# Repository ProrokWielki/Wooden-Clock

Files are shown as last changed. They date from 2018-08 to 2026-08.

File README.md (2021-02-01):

# PROJECT IN PROGRESS #

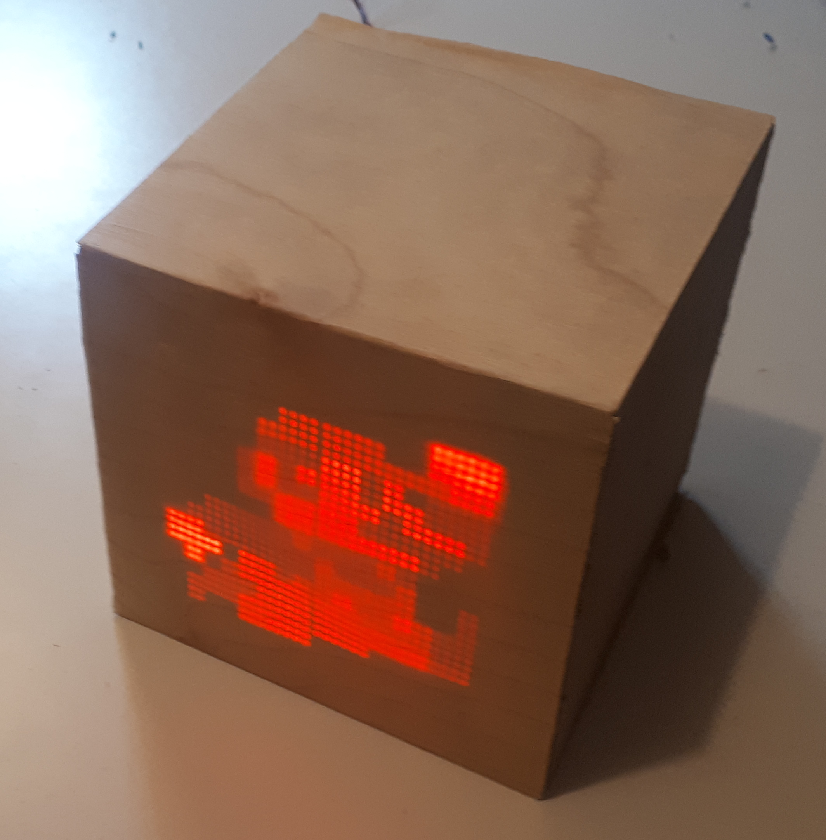
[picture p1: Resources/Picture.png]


A seamless wooden cube with invisble (when turned off) screen.

## how to compile ##

### prerequisites ###

* python >= 3.6
* arm_none_eabi_gcc

### compilation ###

```
git clone https://github.com/ProrokWielki/Wooden-Clock.git
git submodule update --init

pip install py_buildsystem

cd Software/config/py_buildsystem

py_buildsystem -pcc G++_ARM_Config.yaml -pc WoodenClock.yaml
```

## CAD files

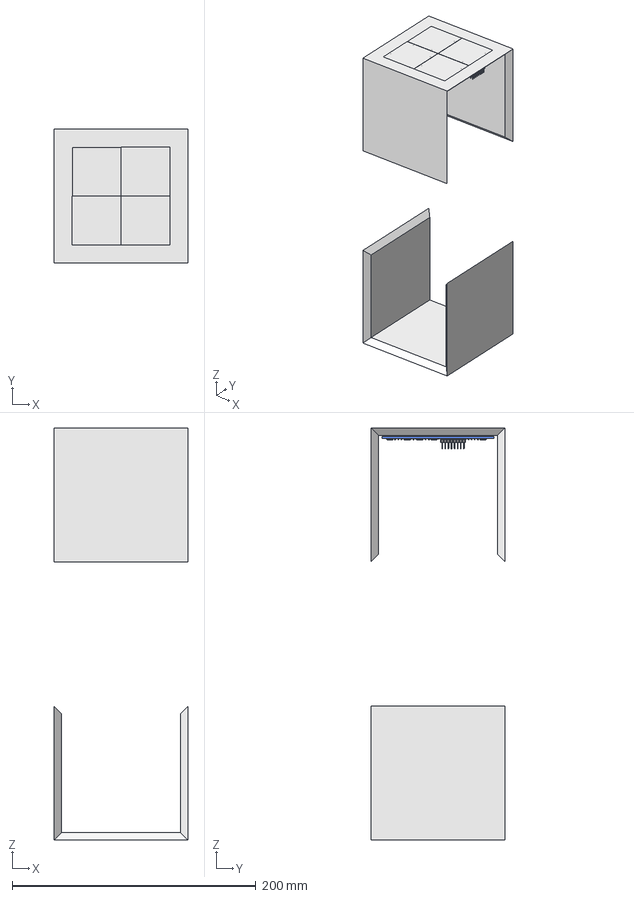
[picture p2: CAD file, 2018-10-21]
Hardware/Casing/Combined.FCStd
110.0 x 110.0 x 338.3 mm
Pcb
R_0805_2012Metric_063
R_0805_2012Metric_064
R_0805_2012Metric_065
R_0805_2012Metric_066
R_0805_2012Metric_067
R_0805_2012Metric_068
R_0805_2012Metric_069
R_0805_2012Metric_070
R_0805_2012Metric_071
R_0805_2012Metric_072
R_0805_2012Metric_073
R_0805_2012Metric_074
R_0805_2012Metric_075
R_0805_2012Metric_076
R_0805_2012Metric_077
R_0805_2012Metric_078
R_0805_2012Metric_079
R_0805_2012Metric_080
R_0805_2012Metric_081
R_0805_2012Metric_082
R_0805_2012Metric_083
R_0805_2012Metric_084
R_0805_2012Metric_085
R_0805_2012Metric_086
R_0805_2012Metric_087
R_0805_2012Metric_088
R_0805_2012Metric_089
R_0805_2012Metric_090
R_0805_2012Metric_091
R_0805_2012Metric_092
R_0805_2012Metric_093
R_0805_2012Metric_094
SOT23_
SOT23_001
SOT23_002
SOT23_003
SOT23_004
SOT23_005
SOT23_006
SOT23_007
SOT23_008
SOT23_009
SOT23_010
SOT23_011
SOT23_012
SOT23_013
SOT23_014
SOT23_015
SOT23_016
SOT23_017
SOT23_018
SOT23_019
SOT23_020
SOT23_021
SOT23_022
SOT23_023
SOT23_024
SOT23_025
SOT23_026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

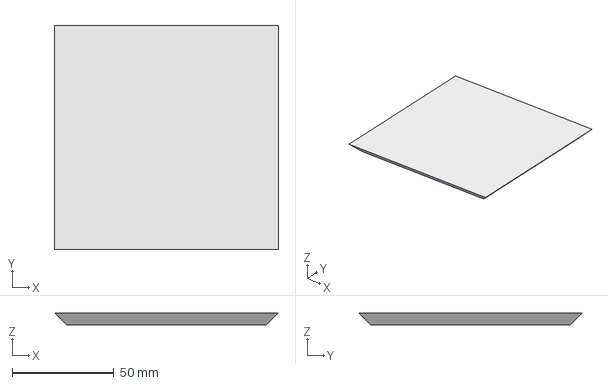
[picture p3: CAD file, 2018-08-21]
Hardware/Casing/SidePlate.FCStd
110.0 x 110.0 x 6.00 mm

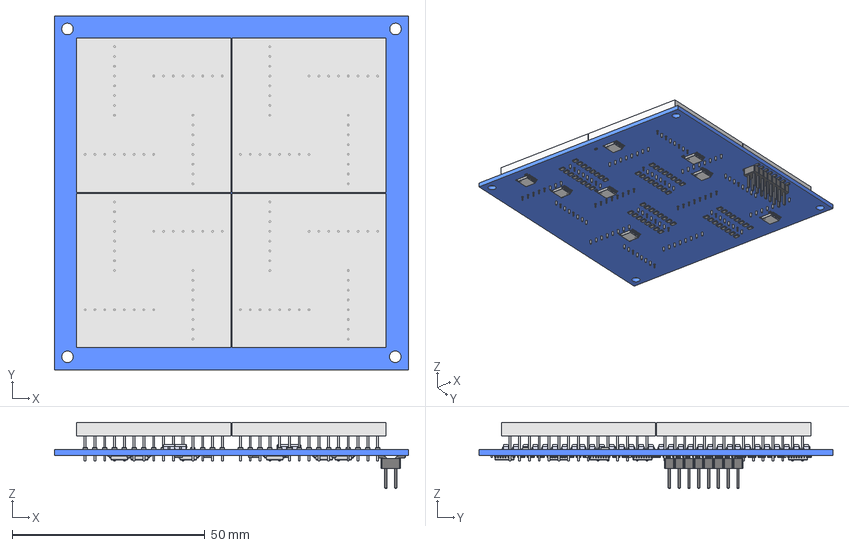
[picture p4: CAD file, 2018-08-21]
Hardware/Casing/DisplayBoard.FCStd
91.8 x 91.6 x 17.1 mm
Pcb
R_0805_2012Metric_063
R_0805_2012Metric_064
R_0805_2012Metric_065
R_0805_2012Metric_066
R_0805_2012Metric_067
R_0805_2012Metric_068
R_0805_2012Metric_069
R_0805_2012Metric_070
R_0805_2012Metric_071
R_0805_2012Metric_072
R_0805_2012Metric_073
R_0805_2012Metric_074
R_0805_2012Metric_075
R_0805_2012Metric_076
R_0805_2012Metric_077
R_0805_2012Metric_078
R_0805_2012Metric_079
R_0805_2012Metric_080
R_0805_2012Metric_081
R_0805_2012Metric_082
R_0805_2012Metric_083
R_0805_2012Metric_084
R_0805_2012Metric_085
R_0805_2012Metric_086
R_0805_2012Metric_087
R_0805_2012Metric_088
R_0805_2012Metric_089
R_0805_2012Metric_090
R_0805_2012Metric_091
R_0805_2012Metric_092
R_0805_2012Metric_093
R_0805_2012Metric_094
SOT23_
SOT23_001
SOT23_002
SOT23_003
SOT23_004
SOT23_005
SOT23_006
SOT23_007
SOT23_008
SOT23_009
SOT23_010
SOT23_011
SOT23_012
SOT23_013
SOT23_014
SOT23_015
SOT23_016
SOT23_017
SOT23_018
SOT23_019
SOT23_020
SOT23_021
SOT23_022
SOT23_023
SOT23_024
SOT23_025
SOT23_026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

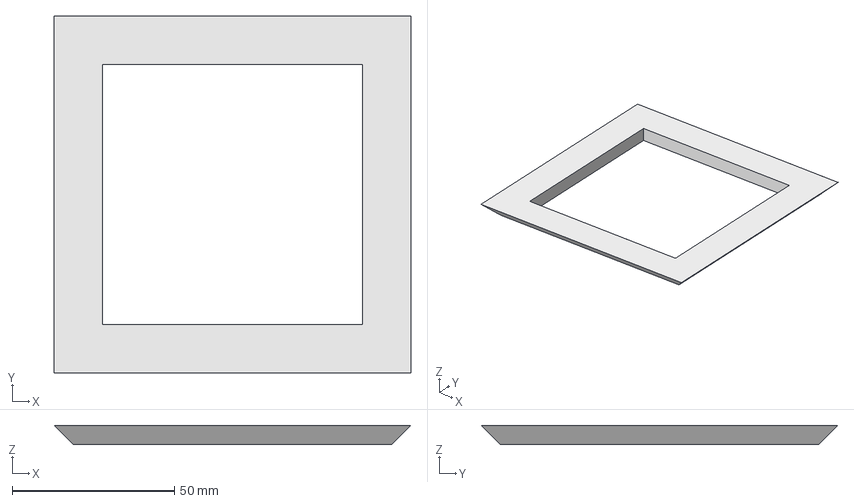
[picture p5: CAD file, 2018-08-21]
Hardware/Casing/FacePlate.FCStd
110.0 x 110.0 x 6.00 mm

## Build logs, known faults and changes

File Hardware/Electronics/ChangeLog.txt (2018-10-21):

0.1.0
  - first releas of the display board

0.1.1
  - fixed swapped drains and sources on the MOSFETs

0.2.0
  - changed P1 from 1x10 header to 2x8 header
  - separated all I2C - all the TLCs can be programed at the same time
  - all I2C are available on the P1

0.2.1
  - silk screens elements arranged
  - added author, board name and board version on the bottom silk screen

1.0.0
  - moved vias from the capacitor pads
  - added github link to silksreen

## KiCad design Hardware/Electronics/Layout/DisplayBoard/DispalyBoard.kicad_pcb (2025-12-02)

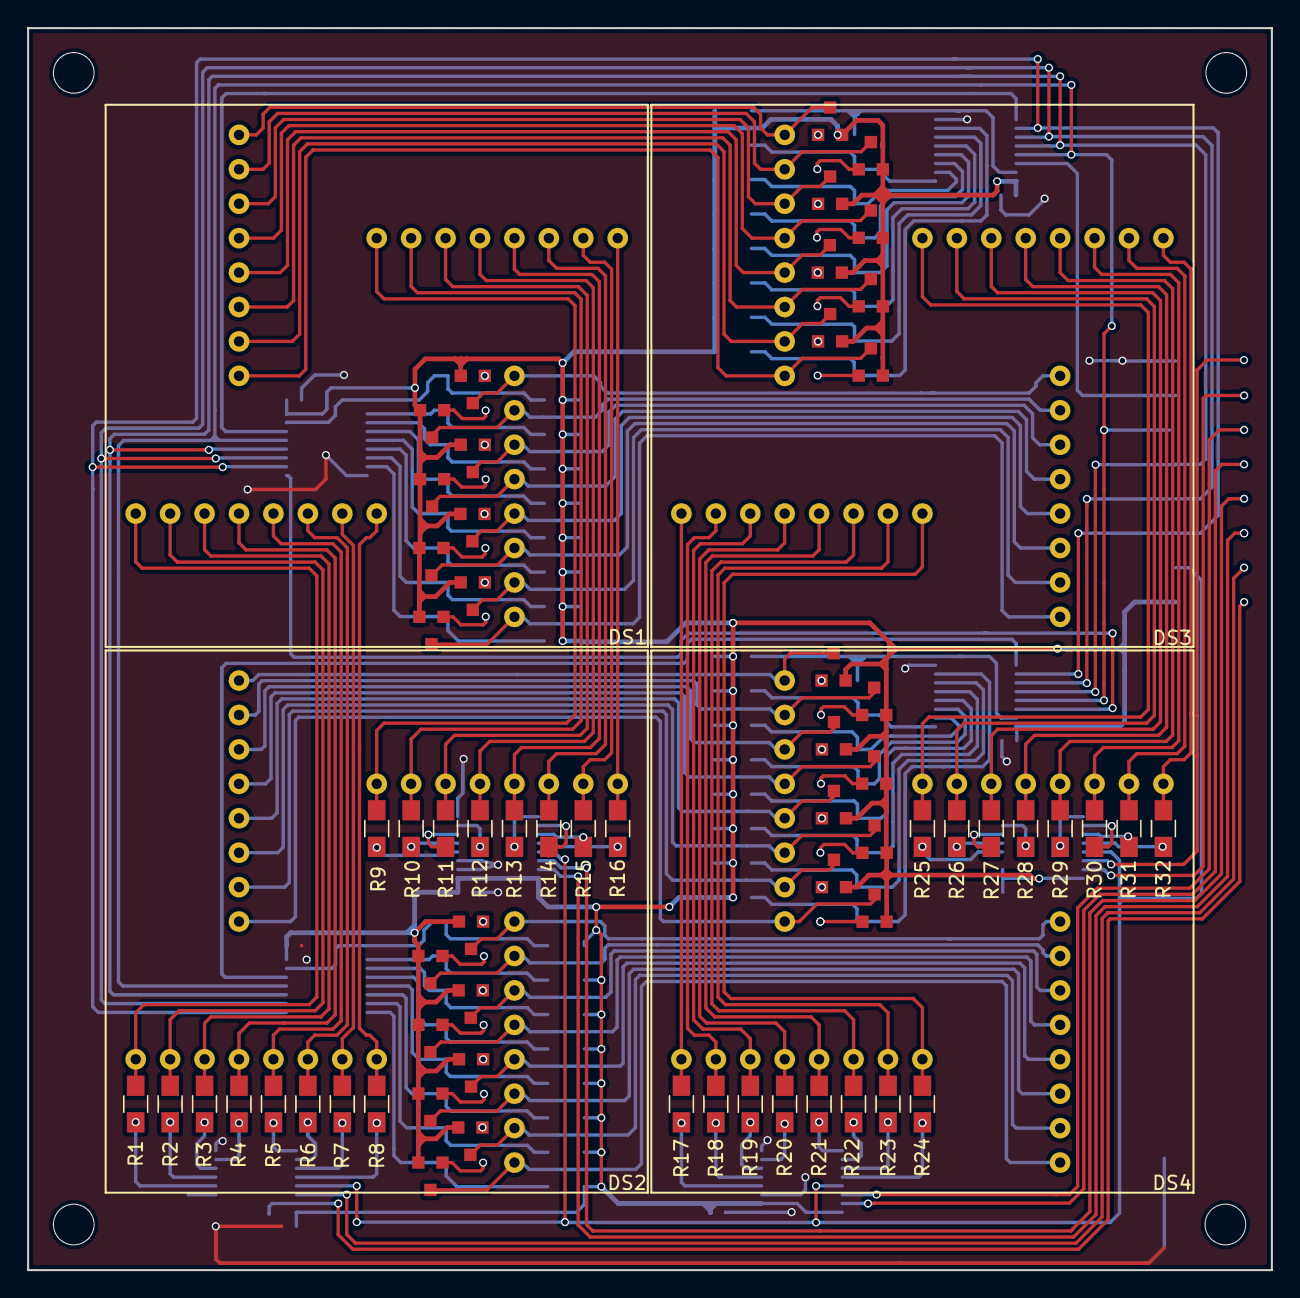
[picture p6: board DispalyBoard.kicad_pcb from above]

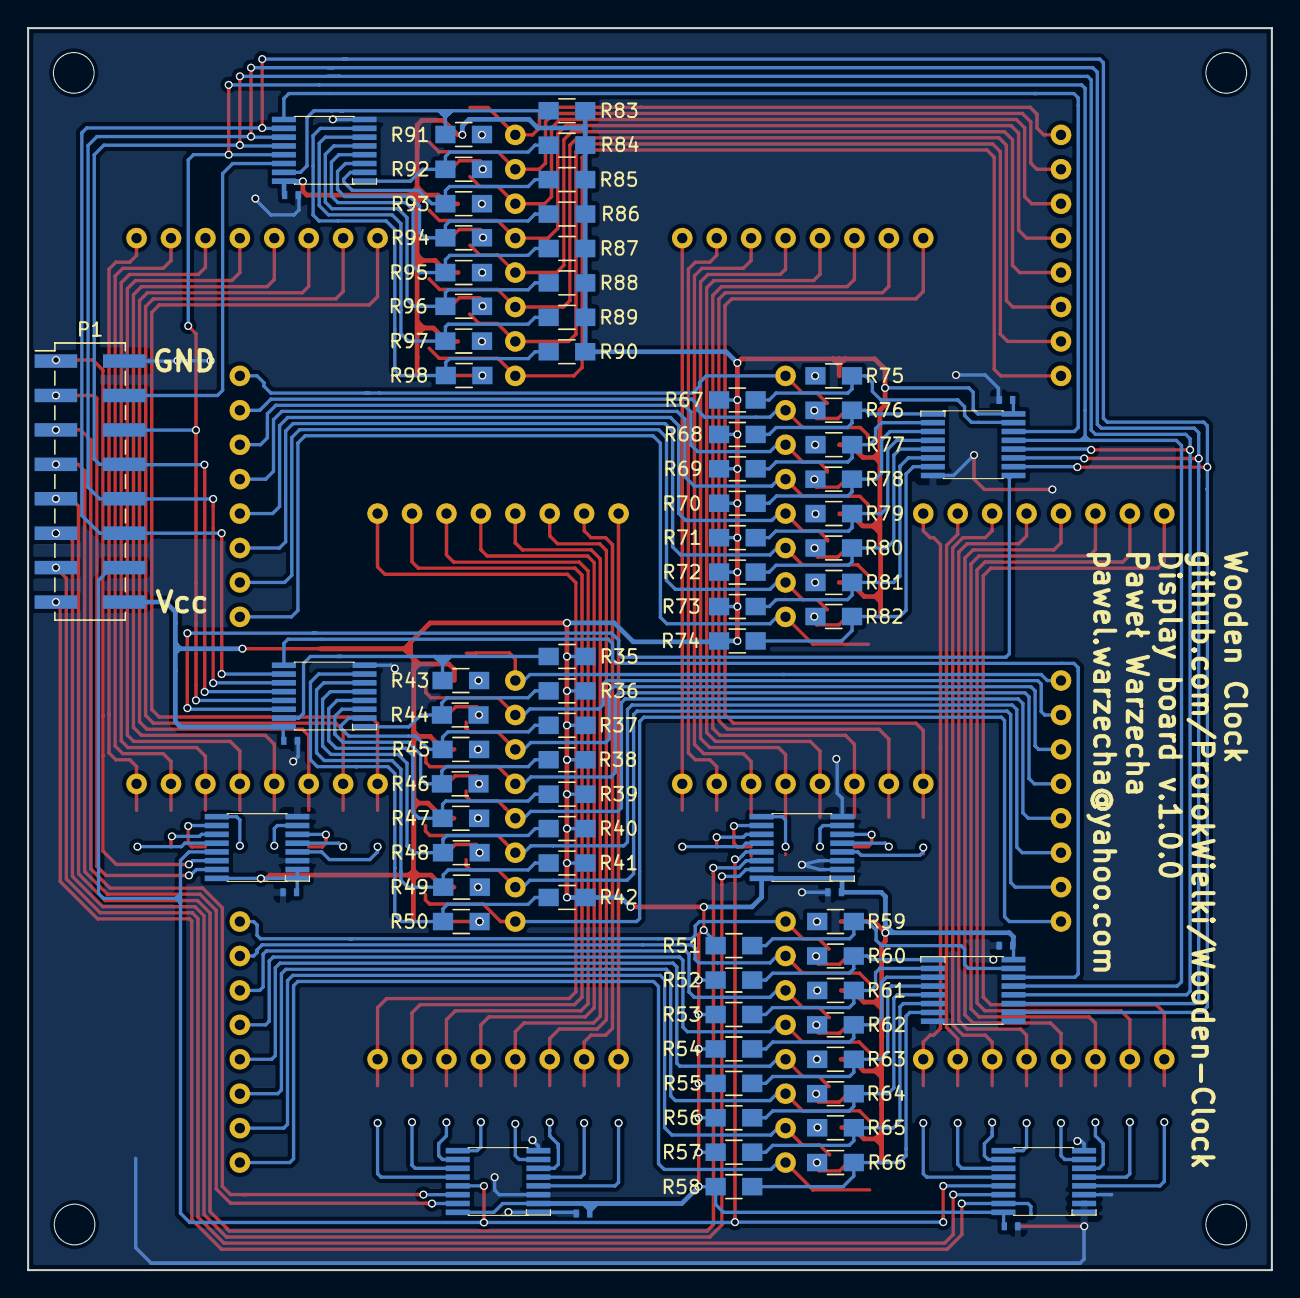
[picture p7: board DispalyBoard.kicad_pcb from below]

Board: 2 copper layers, 91.8 x 91.6 mm, 149 parts (81 on the bottom side), 179 nets.

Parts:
C1, C2, C3, C4, C5, C6, C7, C8: 100n; C0402
DS1, DS2, DS3, DS4: LM-1616015-CC; LM1616X15
P1: CONN_02X08; Pin_Header_Straight_2x08_Pitch2.54mm_SMD
Q1, Q2, Q3, Q4, Q5, Q6, Q7, Q8, Q9, Q10, Q11, Q12, Q13, Q14, Q15, Q16, Q17, Q18, Q19, Q20, Q21, Q22, Q23, Q24, Q25, Q26, Q27, Q28, Q29, Q30, Q31, Q32: TSM3401; SOT23-3
R1, R2, R3, R4, R5, R6, R7, R8, R9, R10, R11, R12, R13, R14, R15, R16, R17, R18, R19, R20, R21, R22, R23, R24, R25, R26, R27, R28, R29, R30, R31, R32: 47; R_0805_HandSoldering
R35, R36, R37, R38, R39, R40, R41, R42, R51, R52, R53, R54, R55, R56, R57, R58, R67, R68, R69, R70, R71, R72, R73, R74, R83, R84, R85, R86, R87, R88, R89, R90: 100k; R_0805_HandSoldering
R43, R44, R45, R46, R47, R48, R49, R50, R59, R60, R61, R62, R63, R64, R65, R66, R75, R76, R77, R78, R79, R80, R81, R82, R91, R92, R93, R94, R95, R96, R97, R98: 100; R_0805_HandSoldering
U1, U2, U3, U4: TLC59208F; TSSOP16
U5, U6, U7, U8: 74HC595; TSSOP16

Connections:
+3V3: C1.1, C2.1, C3.1, C4.1, C5.1, C6.1, C7.1, C8.1, P1.16, Q1.2, Q2.2, Q3.2, Q4.2, Q5.2, Q6.2, Q7.2, Q8.2, Q9.2, Q10.2, Q11.2, Q12.2, Q13.2, Q14.2, Q15.2, Q16.2, Q17.2, Q18.2, Q19.2, Q20.2, Q21.2, Q22.2, Q23.2, Q24.2, Q25.2, Q26.2, Q27.2, Q28.2, Q29.2, Q30.2, Q31.2, Q32.2, R35.1, R36.1, R37.1, R38.1, R39.1, R40.1, R41.1, R42.1, R51.1, R52.1, R53.1, R54.1, R55.1, R56.1, R57.1, R58.1, R67.1, R68.1, R69.1, R70.1, R71.1, R72.1, R73.1, R74.1, R83.1, R84.1, R85.1, R86.1, R87.1, R88.1, R89.1, R90.1, U1.16, U2.1, U2.16, U3.2, U3.16, U4.1, U4.2, U4.16, U5.16, U6.16, U7.16, U8.16
/C1: DS1.1, DS2.1, R1.2
/C2: DS1.2, DS2.2, R2.2
/C3: DS1.3, DS2.3, R3.2
/C4: DS1.4, DS2.4, R4.2
/C5: DS1.5, DS2.5, R5.2
/C6: DS1.6, DS2.6, R6.2
/C7: DS1.7, DS2.7, R7.2
/C8: DS1.8, DS2.8, R8.2
/C9: DS1.24, DS2.24, R9.2
/C10: DS1.23, DS2.23, R10.2
/C11: DS1.22, DS2.22, R11.2
/C12: DS1.21, DS2.21, R12.2
/C13: DS1.20, DS2.20, R13.2
/C14: DS1.19, DS2.19, R14.2
/C15: DS1.18, DS2.18, R15.2
/C16: DS1.17, DS2.17, R16.2
/C17: DS3.1, DS4.1, R17.2
/C18: DS3.2, DS4.2, R18.2
/C19: DS3.3, DS4.3, R19.2
/C20: DS3.4, DS4.4, R20.2
/C21: DS3.5, DS4.5, R21.2
/C22: DS3.6, DS4.6, R22.2
/C23: DS3.7, DS4.7, R23.2
/C24: DS3.8, DS4.8, R24.2
/C25: DS3.24, DS4.24, R25.2
/C26: DS3.23, DS4.23, R26.2
/C27: DS3.22, DS4.22, R27.2
/C28: DS3.21, DS4.21, R28.2
/C29: DS3.20, DS4.20, R29.2
/C30: DS3.19, DS4.19, R30.2
/C31: DS3.18, DS4.18, R31.2
/C32: DS3.17, DS4.17, R32.2
/CLK: P1.10, U5.11, U6.11, U7.11, U8.11
/LAT: P1.8, U5.12, U6.12, U7.12, U8.12
/MosfetMultiplexer9-16/SIN: U7.14, U8.9
/MosfetMultiplexer17-24/SIN: U5.14, U7.9
/MosfetMultiplexer25-32/SIN: U5.9, U6.14
/OE: P1.6, U5.13, U6.13, U7.13, U8.13
/R1: DS1.25, DS3.25, Q25.3
/R2: DS1.26, DS3.26, Q26.3
/R3: DS1.27, DS3.27, Q27.3
/R4: DS1.28, DS3.28, Q28.3
/R5: DS1.29, DS3.29, Q29.3
/R6: DS1.30, DS3.30, Q30.3
/R7: DS1.31, DS3.31, Q31.3
/R8: DS1.32, DS3.32, Q32.3
/R9: DS1.16, DS3.16, Q17.3
/R10: DS1.15, DS3.15, Q18.3
/R11: DS1.14, DS3.14, Q19.3
/R12: DS1.13, DS3.13, Q20.3
/R13: DS1.12, DS3.12, Q21.3
/R14: DS1.11, DS3.11, Q22.3
/R15: DS1.10, DS3.10, Q23.3
/R16: DS1.9, DS3.9, Q24.3
/R17: DS2.25, DS4.25, Q1.3
/R18: DS2.26, DS4.26, Q2.3
/R19: DS2.27, DS4.27, Q3.3
/R20: DS2.28, DS4.28, Q4.3
/R21: DS2.29, DS4.29, Q5.3
/R22: DS2.30, DS4.30, Q6.3
/R23: DS2.31, DS4.31, Q7.3
/R24: DS2.32, DS4.32, Q8.3
/R25: DS2.16, DS4.16, Q9.3
/R26: DS2.15, DS4.15, Q10.3
/R27: DS2.14, DS4.14, Q11.3
/R28: DS2.13, DS4.13, Q12.3
/R29: DS2.12, DS4.12, Q13.3
/R30: DS2.11, DS4.11, Q14.3
/R31: DS2.10, DS4.10, Q15.3
/R32: DS2.9, DS4.9, Q16.3
/RESET: P1.14, U1.13, U2.13, U3.13, U4.13
/RST: P1.12, U5.10, U6.10, U7.10, U8.10
/SCL1: P1.13, U1.14
/SCL2: P1.9, U2.14
/SCL3: P1.5, U3.14
/SCL4: P1.1, U4.14
/SDA1: P1.15, U1.15
/SDA2: P1.11, U2.15
/SDA3: P1.7, U3.15
/SDA4: P1.3, U4.15
/SIN: P1.4, U8.14
GND: C1.2, C2.2, C3.2, C4.2, C5.2, C6.2, C7.2, C8.2, P1.2, U1.1, U1.2, U1.3, U1.8, U2.2, U2.3, U2.8, U3.1, U3.3, U3.8, U4.3, U4.8, U5.8, U6.8, U7.8, U8.8
unnamed: Q1.1, R43.1
unnamed: Q2.1, R44.1
unnamed: Q3.1, R45.1
unnamed: Q4.1, R46.1
unnamed: Q5.1, R47.1
unnamed: Q6.1, R48.1
unnamed: Q7.1, R49.1
unnamed: Q8.1, R50.1
unnamed: Q9.1, R59.1
unnamed: Q10.1, R60.1
unnamed: Q11.1, R61.1
unnamed: Q12.1, R62.1
unnamed: Q13.1, R63.1
unnamed: Q14.1, R64.1
unnamed: Q15.1, R65.1
unnamed: Q16.1, R66.1
unnamed: Q17.1, R75.1
unnamed: Q18.1, R76.1
unnamed: Q19.1, R77.1
unnamed: Q20.1, R78.1
unnamed: Q21.1, R79.1
unnamed: Q22.1, R80.1
unnamed: Q23.1, R81.1
unnamed: Q24.1, R82.1
unnamed: Q25.1, R91.1
unnamed: Q26.1, R92.1
unnamed: Q27.1, R93.1
unnamed: Q28.1, R94.1
unnamed: Q29.1, R95.1
unnamed: Q30.1, R96.1
unnamed: Q31.1, R97.1
unnamed: Q32.1, R98.1
unnamed: R1.1, U1.4
unnamed: R2.1, U1.5
unnamed: R3.1, U1.6
unnamed: R4.1, U1.7
unnamed: R5.1, U1.9
unnamed: R6.1, U1.10
unnamed: R7.1, U1.11
unnamed: R8.1, U1.12
unnamed: R9.1, U2.4
unnamed: R10.1, U2.5
unnamed: R11.1, U2.6
unnamed: R12.1, U2.7
unnamed: R13.1, U2.9
unnamed: R14.1, U2.10
unnamed: R15.1, U2.11
unnamed: R16.1, U2.12
unnamed: R17.1, U3.4
unnamed: R18.1, U3.5
unnamed: R19.1, U3.6
unnamed: R20.1, U3.7
unnamed: R21.1, U3.9
unnamed: R22.1, U3.10
unnamed: R23.1, U3.11
unnamed: R24.1, U3.12
unnamed: R25.1, U4.4
unnamed: R26.1, U4.5
unnamed: R27.1, U4.6
unnamed: R28.1, U4.7
unnamed: R29.1, U4.9
unnamed: R30.1, U4.10
unnamed: R31.1, U4.11
unnamed: R32.1, U4.12
unnamed: R35.2, R43.2, U5.15
unnamed: R36.2, R44.2, U5.1
unnamed: R37.2, R45.2, U5.2
unnamed: R38.2, R46.2, U5.3
unnamed: R39.2, R47.2, U5.4
unnamed: R40.2, R48.2, U5.5
unnamed: R41.2, R49.2, U5.6
unnamed: R42.2, R50.2, U5.7
unnamed: R51.2, R59.2, U6.15
unnamed: R52.2, R60.2, U6.1
unnamed: R53.2, R61.2, U6.2
unnamed: R54.2, R62.2, U6.3
unnamed: R55.2, R63.2, U6.4
unnamed: R56.2, R64.2, U6.5
unnamed: R57.2, R65.2, U6.6
unnamed: R58.2, R66.2, U6.7
unnamed: R67.2, R75.2, U7.15
unnamed: R68.2, R76.2, U7.1
unnamed: R69.2, R77.2, U7.2
unnamed: R70.2, R78.2, U7.3
unnamed: R71.2, R79.2, U7.4
unnamed: R72.2, R80.2, U7.5
unnamed: R73.2, R81.2, U7.6
unnamed: R74.2, R82.2, U7.7
unnamed: R83.2, R91.2, U8.15
unnamed: R84.2, R92.2, U8.1
unnamed: R85.2, R93.2, U8.2
unnamed: R86.2, R94.2, U8.3
unnamed: R87.2, R95.2, U8.4
unnamed: R88.2, R96.2, U8.5
unnamed: R89.2, R97.2, U8.6
unnamed: R90.2, R98.2, U8.7

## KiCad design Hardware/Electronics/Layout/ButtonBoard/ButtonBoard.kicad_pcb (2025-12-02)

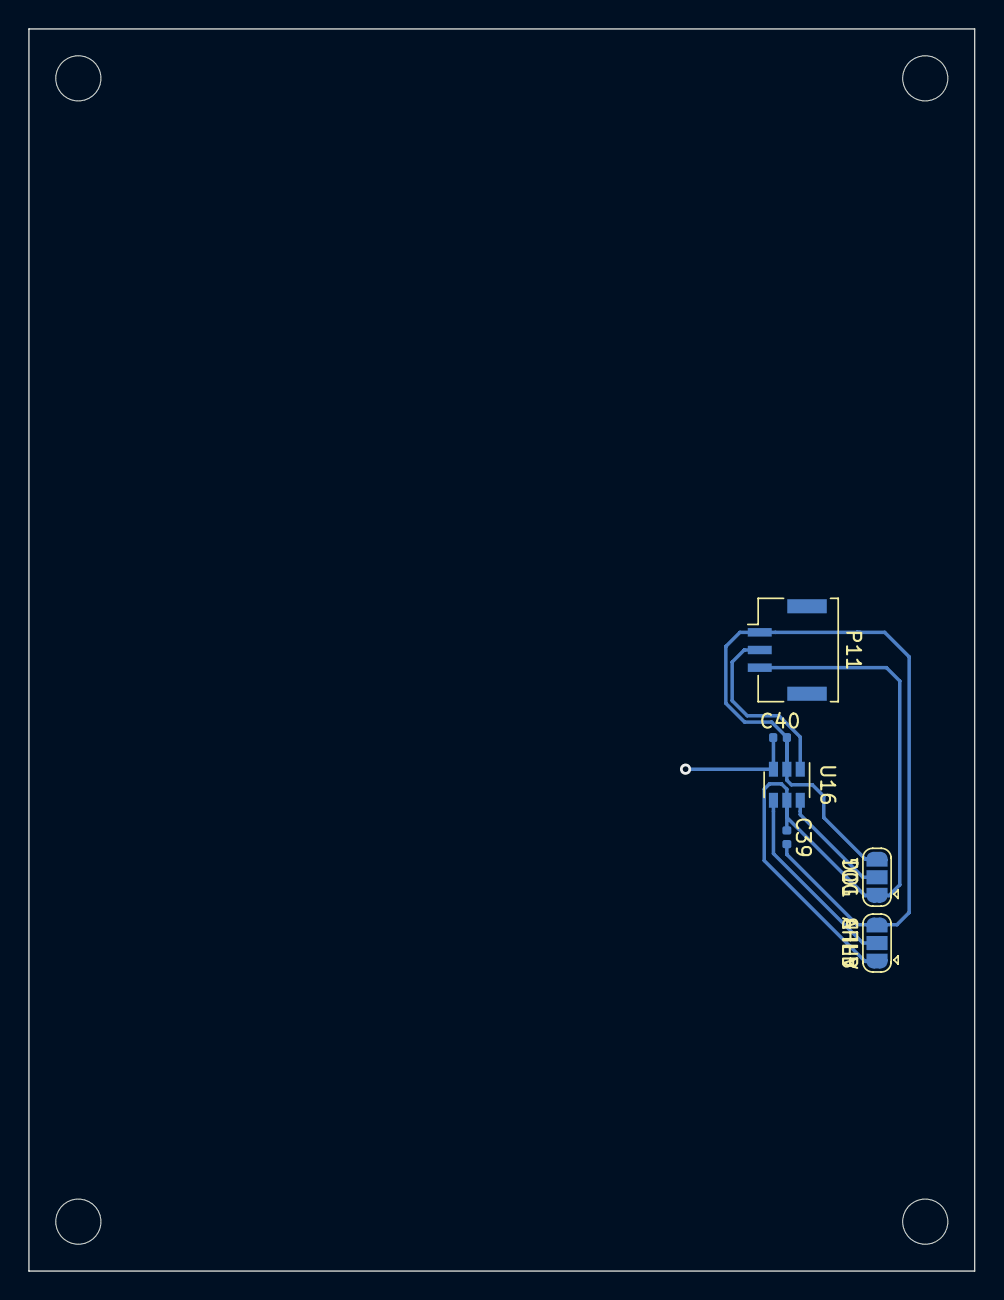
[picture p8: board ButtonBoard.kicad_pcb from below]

Board: 2 copper layers, 67.0 x 88.0 mm, 6 parts (6 on the bottom side), 6 nets.

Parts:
AHLB: AHLB; SolderJumper-3_P1.3mm_Open_RoundedPad1.0x1.5mm
C39: 1u; C_0402_1005Metric
C40: <50p; C_0402_1005Metric
P11: CONN_01X03; Molex_CLIK-Mate_502382-0370_1x03-1MP_P1.25mm_Vertical
TOG: TOG; SolderJumper-3_P1.3mm_Open_RoundedPad1.0x1.5mm
U16: TTP223; SOT-23-6

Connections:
+3V3: AHLB.1, C39.1, P11.3, TOG.1, U16.5
GND: AHLB.3, C39.2, C40.2, P11.1, TOG.3, U16.2
unnamed: AHLB.2, U16.4
unnamed: TOG.2, U16.6
OUTPUT: P11.2, U16.1
PAD: C40.1, U16.3

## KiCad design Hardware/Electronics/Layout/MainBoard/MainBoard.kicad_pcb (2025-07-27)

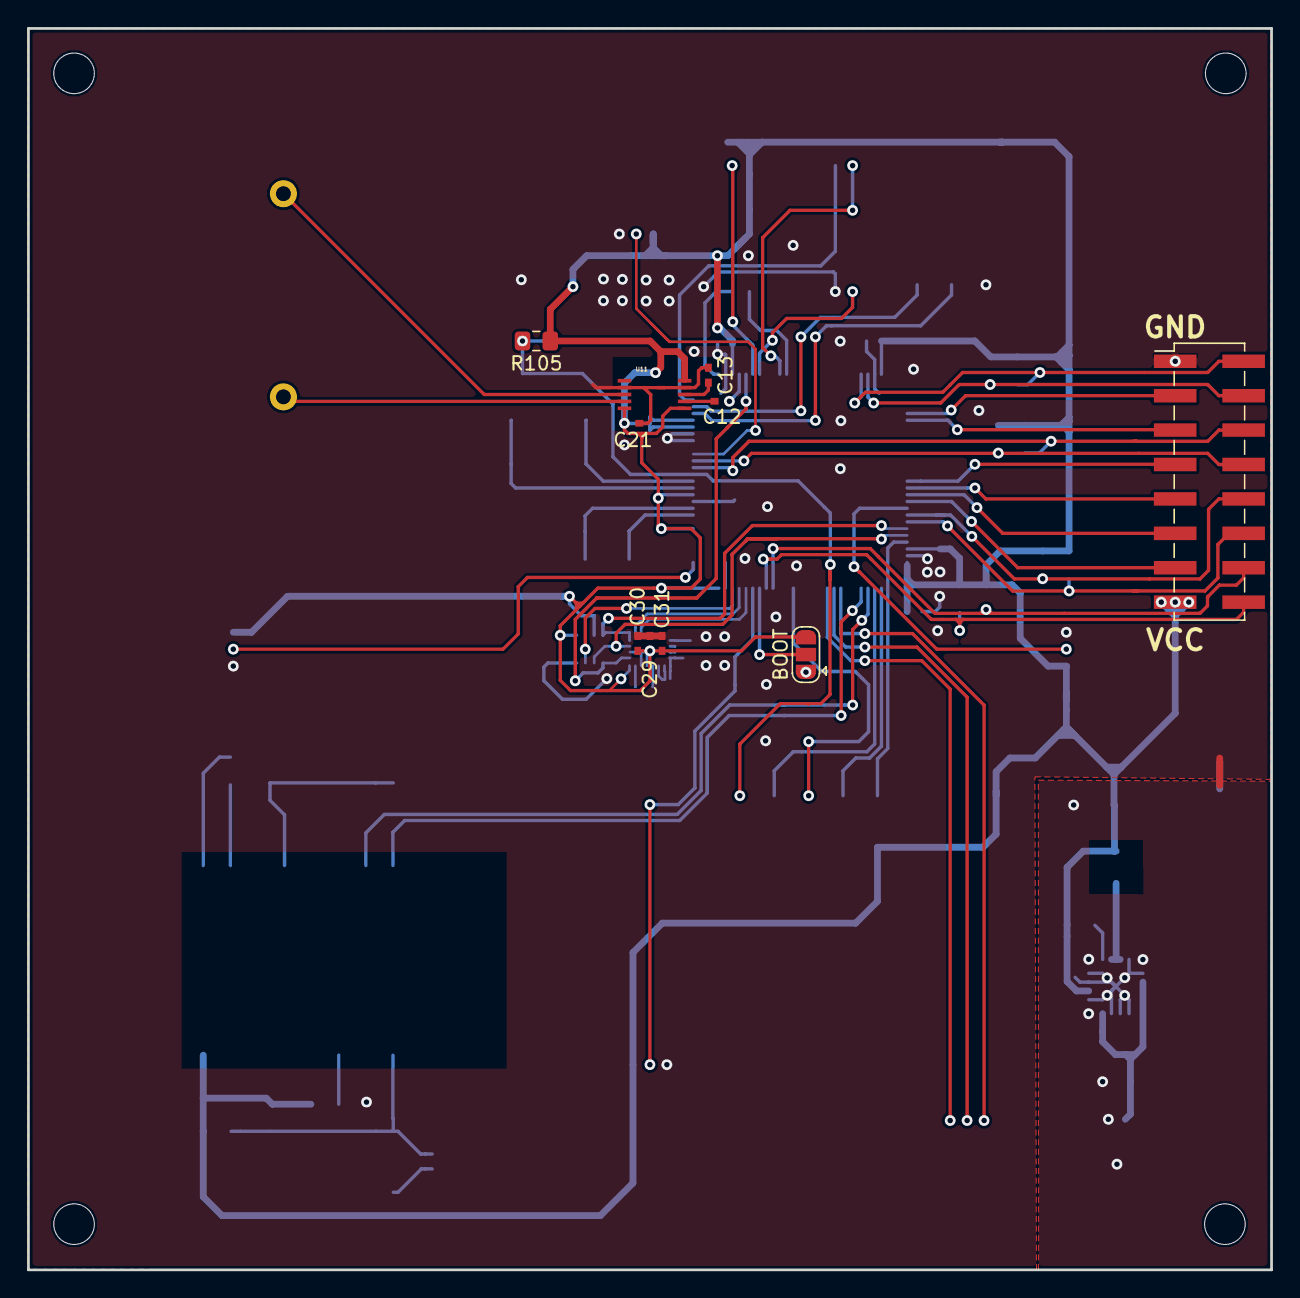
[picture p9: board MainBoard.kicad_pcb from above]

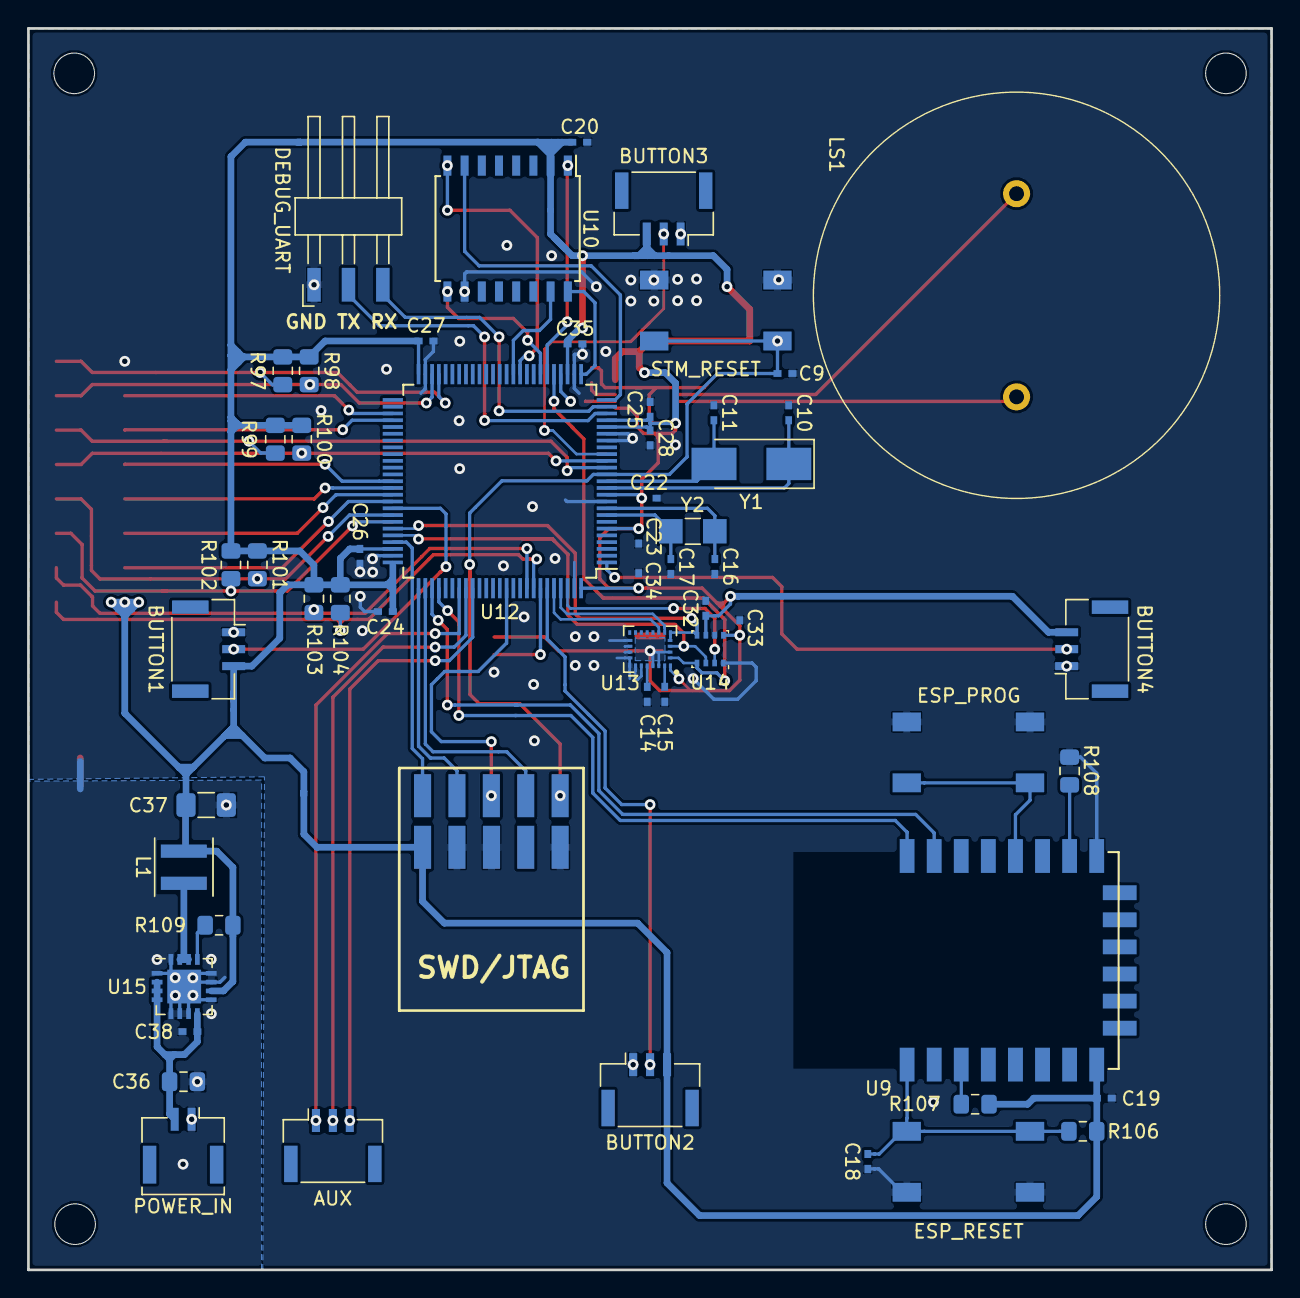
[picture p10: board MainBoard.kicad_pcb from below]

Board: 2 copper layers, 91.8 x 91.6 mm, 67 parts (57 on the bottom side), 63 nets.

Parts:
C9, C15, C18, C19, C20, C22, C23, C24, C25, C26, C27, C28, C30, C31, C32, C33, C34, C35: 100n; C_0402_NoSilk
C10, C11: 7.5p; C_0402_NoSilk
C12, C13, C21, C38: 1u; C_0402_NoSilk
C14: 10n; C_0402_NoSilk
C16, C17: 4pF; C_0402_NoSilk
C29: 10u; C_0402_NoSilk
C36: 10u; C_0805_2012Metric_Pad1.15x1.40mm_HandSolder
C37: 22u; C_1206_3216Metric_Pad1.42x1.75mm_HandSolder
JP1: BOOT; SolderJumper-3_P1.3mm_Open_RoundedPad1.0x1.5mm
L1: 6u8; L_Coilcraft_XxL4040
LS1: BDT3016H12
P2: CONN_02X08; Pin_Header_Straight_2x08_Pitch2.54mm_SMD
P3: SWD/JTAG; SAMTEC-TSM-105-01-X-DH
P4: BUTTON1; Molex_CLIK-Mate_502386-0370_1x03-1MP_P1.25mm_Horizontal
P5: BUTTON2; Molex_CLIK-Mate_502386-0370_1x03-1MP_P1.25mm_Horizontal
P6: BUTTON3; Molex_CLIK-Mate_502386-0370_1x03-1MP_P1.25mm_Horizontal
P7: BUTTON4; Molex_CLIK-Mate_502386-0370_1x03-1MP_P1.25mm_Horizontal
P8: POWER_IN; Molex_CLIK-Mate_502382-0270_1x02-1MP_P1.25mm_Vertical
P9: DEBUG_UART; Harwin_M20-89003xx_1x03_P2.54mm_Horizontal
P10: AUX; Molex_CLIK-Mate_502386-0370_1x03-1MP_P1.25mm_Horizontal
R97, R98, R99, R100, R101, R102, R103, R104, R105, R106, R107, R108: 4k7; R_0805_2012Metric_Pad1.15x1.40mm_HandSolder
R109: 1M; C_0805_2012Metric_Pad1.15x1.40mm_HandSolder
SW1: STM_RESET; E-switch_6x6mm
SW2: ESP_RESET; E-switch_6x6mm
SW3: ESP_PROG; E-switch_6x6mm
U9: ESP-12F; ESP-12E_SMD
U10: S25FL129P; SOIC-16W_7.5x10.3mm_P1.27mm
U11: MAX9700; MSOP10-0.5
U12: STM32L452VCTx; LQFP-100_14x14mm_P0.5mm
U13: LSM9DS1; LGA-24L_3x3.5mm_P0.43mm
U14: BME280; Bosch_LGA-8_2.5x2.5mm_P0.65mm_ClockwisePinNumbering
U15: TPS6211; QFN-16-1EP_4x4mm_P0.65mm_EP2.5x2.5mm
Y1: 8MHz; Crystal_SMD_Abracon_ABM3-2Pin_5.0x3.2mm_HandSoldering
Y2: 32.768kHz; Crystal_SMD_MicroCrystal_CC7V-T1A-2Pin_3.2x1.5mm_HandSolder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

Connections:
+3V3: C19.1, C20.2, C21.2, C22.2, C23.2, C24.2, C25.2, C26.2, C27.2, C28.2, C29.2, C30.2, C31.2, C32.2, C33.2, C34.2, C35.2, C37.1, JP1.3, L1.2, P2.15, P3.1, P4.3, P5.3, P6.3, P7.3, R97.1, R98.1, R99.1, R100.1, R101.1, R102.1, R103.1, R104.1, R105.1, R106.1, R107.1, R109.1, U9.8, U10.2, U11.1, U11.5, U11.10, U12.6, U12.11, U12.21, U12.22, U12.28, U12.50, U12.73, U12.75, U12.100, U13.1, U13.3, U13.22, U13.23, U14.6, U14.8, U15.10
/DisplayBoard/DATA_IN: P2.3, U12.53
/DisplayBoard/LATCH: P2.7, U12.63
/DisplayBoard/SCL1: P2.10, R101.2, U12.68
/DisplayBoard/SCL2: P2.2, R97.2, U12.47
/DisplayBoard/SCL3: P2.6, R99.2, U12.15
/DisplayBoard/SCL4: P2.14, R103.2, U12.92
/DisplayBoard/SDA1: P2.12, R102.2, U12.69
/DisplayBoard/SDA2: P2.4, R98.2, U12.48
/DisplayBoard/SDA3: P2.8, R100.2, U12.16
/DisplayBoard/SDA4: P2.16, R104.2, U12.93
/MainBoard/CLOCK: P2.9, U12.64
/MainBoard/CS: U10.7, U12.25
/MainBoard/IO0: U10.15, U12.36
/MainBoard/IO1: U10.8, U12.35
/MainBoard/IO2: U10.9, U12.32
/MainBoard/IO3: U10.1, U12.31
/MainBoard/OE: P2.5, U12.54
/MainBoard/RESET: P2.11, U12.65
/MainBoard/RST: P2.13, U12.66
/MainBoard/SCK: U10.16, U12.26
/MainBoard/SPI1_CS1: U12.97, U13.7
/MainBoard/SPI1_CS2: U12.96, U13.8
/MainBoard/SPI1_CS3: U12.98, U14.2
/MainBoard/SPI1_MISO: U12.70, U13.5, U13.6, U14.5
/MainBoard/SPI1_MOSI: U12.71, U13.4, U14.3
/MainBoard/SPI1_SCK: U12.30, U13.2, U14.4
/MainBoard/TCK: P3.4, U12.76
/MainBoard/TDI: P3.8, U12.77
/MainBoard/TDO: P3.6, U12.89
/MainBoard/TMS: P3.2, U12.72
AUX_1: P10.1, U12.82
AUX_2: P10.2, U12.83
AUX_3: P10.3, U12.84
BUTTON1: P4.2, U12.67
BUTTON2: P5.2, U12.95
BUTTON3: P6.2, U12.17
BUTTON4: P7.2, U12.1
ESP_RX: U9.15, U12.78
ESP_TX: U9.16, U12.79
GND: C9.2, C10.2, C11.2, C13.1, C14.2, C15.2, C16.1, C17.1, C18.2, C19.2, C20.1, C21.1, C22.1, C23.1, C24.1, C25.1, C26.1, C27.1, C28.1, C29.1, C30.1, C31.1, C32.1, C33.1, C34.1, C35.1, C36.2, C37.2, C38.2, JP1.1, P2.1, P3.3, P3.5, P3.9, P4.1, P5.1, P6.1, P7.1, P8.1, P9.1, R108.2, SW1.1, SW2.1, SW3.2, U9.9, U10.10, U11.4, U11.7, U12.10, U12.19, U12.20, U12.27, U12.49, U12.74, U12.99, U13.14, U13.15, U13.16, U13.17, U13.18, U13.19, U13.20, U14.1, U14.7, U15.1, U15.5, U15.6, U15.7, U15.9, U15.11, U15.12, U15.16, U15.17
NRST: C9.1, P3.10, R105.2, SW1.2, U12.14
unnamed: C10.1, U12.12, Y1.1
unnamed: C11.1, U12.13, Y1.2
unnamed: C12.1, U11.2
unnamed: C12.2, U12.29
unnamed: C13.2, U11.3
unnamed: C14.1, U13.21
unnamed: C15.1, U13.24
unnamed: C16.2, U12.9, Y2.2
unnamed: C17.2, U12.8, Y2.1
unnamed: C18.1, R106.2, SW2.2, U9.1
unnamed: C36.1, C38.1, P8.2, U15.2, U15.3, U15.4, U15.8
unnamed: JP1.2, U12.94
unnamed: L1.1, U15.14, U15.15
unnamed: LS1.1, U11.8
unnamed: LS1.2, U11.9
unnamed: P9.2, U12.23
unnamed: P9.3, U12.24
unnamed: R107.2, U9.3
unnamed: R108.1, U9.10
unnamed: R109.2, U15.13
unnamed: SW3.1, U9.12

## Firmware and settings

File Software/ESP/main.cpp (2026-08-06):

#include <Arduino.h>
#include <ESP8266WiFi.h>
#include <pb_encode.h>
#include <time.h>

#include "esp_msg.pb.h"

#include <functional>
#include <map>
#include <string>

#include "config/mqtt_config.h"
#include "config/wifi_config.h"

#include "helpers/mqtt.h"
#include "helpers/ota.h"

WiFiClient wifi_;
PubSubClient mqtt_(mqtt::server_ip, mqtt::server_port, wifi_);

std::map<std::string, std::function<void(byte * payload, unsigned int length)>> handle_topic{
{"up", [](byte * payload, unsigned int length) { Serial.print("u"); }},
{"down", [](byte * payload, unsigned int length) { Serial.print("d"); }},
{"left", [](byte * payload, unsigned int length) { Serial.print("l"); }},
{"reset", [](byte * payload, unsigned int length) { Serial.print("w"); }},
{"right", [](byte * payload, unsigned int length) { Serial.print("r"); }},
{"test",
 [](byte * payload, unsigned int length) {
     time_t now = time(nullptr);
     struct tm * timeinfo = localtime(&now);

     EspToMcuMsg msg = EspToMcuMsg_init_zero;
     msg.which_msg = EspToMcuMsg_time_tag;

     msg.msg.time.hours = timeinfo->tm_hour;
     msg.msg.time.minutes = timeinfo->tm_min;
     msg.msg.time.seconds = timeinfo->tm_sec;
     uint8_t buffer[EspToMcuMsg_size];
     pb_ostream_t stream = pb_ostream_from_buffer(buffer, sizeof(buffer));
     pb_encode(&stream, EspToMcuMsg_fields, &msg);
     Serial.write(buffer, stream.bytes_written);
 }},
};

const char * TZ_INFO = "CET-1CEST,M3.5.0/2,M10.5.0/3";

void setup()
{
    Serial.begin(500000);

    ota::initialize();

    WiFi.hostname(wifi::hostname);
    WiFi.begin(wifi::ssid, wifi::password);
    while (WiFi.status() != WL_CONNECTED)
    {
        delay(500);
    }

    while (not mqtt_.connect(mqtt::client_id))
    {
        delay(500);
    }

    mqtt_.setCallback([](char * topic, byte * payload, unsigned int length) { handle_topic[topic](payload, length); });
    mqtt::subscribe(mqtt_, handle_topic);

    configTime(TZ_INFO, "tempus1.gum.gov.pl", "pl.pool.ntp.org");

    Serial.println("----- setup done --------");
}

void loop()
{
    ota::handle();
    mqtt_.loop();
}

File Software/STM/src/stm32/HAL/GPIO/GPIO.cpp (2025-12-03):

/**
 *  @file GPIO.cpp
 *
 *  Created on: 02-02-2025
 *  @author: Paweł Warzecha
 */

#include <cstdint>

#include <HAL/Clock.hpp>
#include <HAL/Register.hpp>
#include <HAL/SysConfig.hpp>
#include <HAL/types.hpp>

#include "include/HAL/GPIO.hpp"

#include <cmsis_bridge/cmsis_bridge.hpp>

namespace
{
constexpr static uint8_t MODER_FIELD_BIT_LENGTH = 2;
constexpr static uint8_t OTYPER_FIELD_BIT_LENGTH = 1;
constexpr static uint8_t OSPEEDR_FIELD_BIT_LENGTH = 2;
constexpr static uint8_t PUPDR_FIELD_BIT_LENGTH = 2;
constexpr static uint8_t ODR_FIELD_BIT_LENGTH = 1;
constexpr static uint8_t AFR_FIELD_BIT_LENGTH = 4;

constexpr static uint8_t AFRH_START_FIELD = 8;
}  // namespace

using namespace GPIO_Types;

GPIO::GPIO(Clock & clock, SysConfig & sys_config, Port port, const uint8_t pin_number)
: clock_{clock}, sys_config_(sys_config), MODER(to_address(port, PortRegister::MODER)), OTYPER(to_address(port, PortRegister::OTYPER)),
  OSPEEDR(to_address(port, PortRegister::OSPEEDR)), PUPDR(to_address(port, PortRegister::PUPDR)), AFRL(to_address(port, PortRegister::AFRL)),
  AFRH(to_address(port, PortRegister::AFRH)), BSRR(to_address(port, PortRegister::BSRR)), BRR(to_address(port, PortRegister::BRR)),
  ODR(to_address(port, PortRegister::ODR)), IDR(to_address(port, PortRegister::IDR)), port_{port}, pin_number_(pin_number)
{
    clock_.enable_clock_for(to_peripheral(port));
};

void GPIO::set_mode(PortMode PortMode)
{
    MODER.set_value(to_register_value(PortMode), pin_number_ * MODER_FIELD_BIT_LENGTH, MODER_FIELD_BIT_LENGTH);
}

void GPIO::set_output_type(PortOutputType portOutputType)
{
    OTYPER.set_value(to_register_value(portOutputType), pin_number_ * OTYPER_FIELD_BIT_LENGTH, OTYPER_FIELD_BIT_LENGTH);
}

void GPIO::set_speed(PortOutputSpeed portOutputSpeed)
{
    OSPEEDR.set_value(to_register_value(portOutputSpeed), pin_number_ * OSPEEDR_FIELD_BIT_LENGTH, OSPEEDR_FIELD_BIT_LENGTH);
}

void GPIO::set_pull_up_pull_down(PortPullUpPullDown PortPullUpPullDown)
{
    PUPDR.set_value(to_register_value(PortPullUpPullDown), pin_number_ * PUPDR_FIELD_BIT_LENGTH, PUPDR_FIELD_BIT_LENGTH);
}

void GPIO::set_alternate_function(AlternateFunction alternateFunction)
{
    constexpr uint8_t AFRH_START_PIN_NUMBER{8};
    if (pin_number_ >= AFRH_START_PIN_NUMBER)
    {
        AFRH.set_value(to_register_value(alternateFunction), (pin_number_ - AFRH_START_FIELD) * AFR_FIELD_BIT_LENGTH, AFR_FIELD_BIT_LENGTH);
    }
    else
    {
        AFRL.set_value(to_register_value(alternateFunction), pin_number_ * AFR_FIELD_BIT_LENGTH, AFR_FIELD_BIT_LENGTH);
    }
}

void GPIO::set_output_value(SignalLevel signalLevel)
{
    ODR.set_value(to_register_value(signalLevel), pin_number_ * ODR_FIELD_BIT_LENGTH, ODR_FIELD_BIT_LENGTH);
}

void GPIO::set_output_high()
{
    ODR.set_bit(pin_number_);
}

void GPIO::set_output_low()
{
    ODR.clear_bit(pin_number_);
}

void GPIO::toggle_output_value()
{
    ODR.toggle_bit(pin_number_);
}

SignalLevel GPIO::get_input_value()
{
    return IDR.get_bit(pin_number_) == 1 ? SignalLevel::High : SignalLevel::Low;
}

void GPIO::set_as_i2c_pin(AlternateFunction AlternateFunction)
{
    set_alternate_function(AlternateFunction);
    set_pull_up_pull_down(PortPullUpPullDown::PullUp);
    set_mode(PortMode::Alternate);
    set_output_type(PortOutputType::OpenDrain);
    set_speed(PortOutputSpeed::VeryHigh);
}

void GPIO::set_as_spi_pin(AlternateFunction AlternateFunction)
{
    set_alternate_function(AlternateFunction);
    set_mode(PortMode::Alternate);
    set_output_type(PortOutputType::PushPull);
    set_pull_up_pull_down(PortPullUpPullDown::None);
    set_speed(PortOutputSpeed::VeryHigh);
}

void GPIO::set_fast_mode_plus()
{
    sys_config_.set_fast_mode_plus(port_, pin_number_);
}

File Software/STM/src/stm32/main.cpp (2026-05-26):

#include "APP.hpp"
#include <BSP/BSP.hpp>
#include <HAL/HAL.hpp>

#include <stm32l452xx.h>

int main()
{
    HAL::get().init();
    BSP::get().init();

    BSP::get().display.set_frame_buffer(BSP::get().frame_buffer1);

    NVIC_EnableIRQ(DMA1_Channel2_IRQn);
    NVIC_EnableIRQ(DMA1_Channel4_IRQn);
    NVIC_EnableIRQ(DMA2_Channel7_IRQn);
    NVIC_EnableIRQ(DMA2_Channel2_IRQn);
    NVIC_EnableIRQ(USART3_IRQn);
    NVIC_EnableIRQ(UART4_IRQn);
    NVIC_EnableIRQ(TIM2_IRQn);

    app_init();

    for (;;)
    {
    }
    return 0;
}

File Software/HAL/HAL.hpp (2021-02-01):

/**
 *  @file HAL.hpp
 *
 *  Created on: 21-11-2018
 *  @author: Paweł Warzecha
 */

#ifndef HAL_HAL_HPP_
#define HAL_HAL_HPP_

#include "Clock/Clock.hpp"
#include "DMA/DMA.hpp"
#include "GPIO/GPIO.hpp"
#include "I2C/I2C.hpp"
#include "SPI/SPI.hpp"
#include "Timer/Timer.hpp"

#include "74HC595/74HC595.hpp"
#include "BME280/BME280.hpp"
#include "LSM9DS1/LSM9DS1.hpp"
#include "TLC59208F/TLC59208F.hpp"

class LSM9DS1;

class HAL
{
public:
    static GPIO I2C1_SCL;
    static GPIO I2C1_SDA;

    static GPIO I2C2_SCL;
    static GPIO I2C2_SDA;

    static GPIO I2C3_SCL;
    static GPIO I2C3_SDA;

    static GPIO I2C4_SCL;
    static GPIO I2C4_SDA;

    static GPIO SPI1_MISO;
    static GPIO SPI1_MOSI;
    static GPIO SPI1_SCK;
    static GPIO SPI1_CS1;
    static GPIO SPI1_CS2;
    static GPIO SPI1_CS3;

    static GPIO QSPI_IO0;
    static GPIO QSPI_IO1;
    static GPIO QSPI_IO2;
    static GPIO QSPI_IO3;
    static GPIO QSPI_CLK;
    static GPIO QSPI_CS;

    static GPIO UART3_TX;
    static GPIO UART3_RX;

    static GPIO UART4_TX;
    static GPIO UART4_RX;

    static GPIO TLC_RESET;

    static GPIO SR_DATAIN;
    static GPIO SR_RCLOCK;
    static GPIO SR_SCLOCK;
    static GPIO SR_OE;
    static GPIO SR_CLEAR;

    static GPIO BUTTON1;
    static GPIO BUTTON2;
    static GPIO BUTTON3;
    static GPIO BUTTON4;

    static DMA DMA1_2;
    static DMA DMA1_4;
    static DMA DMA2_2;
    static DMA DMA2_7;
    static DMA DMA2_4;

    static I2C I2C_1;
    static I2C I2C_2;
    static I2C I2C_3;
    static I2C I2C_4;

    static SPI SPI_1;

    static SR_74HC595 SR_74HC595_1;

    static TLC59208F TLC59208F_1;
    static TLC59208F TLC59208F_2;
    static TLC59208F TLC59208F_3;
    static TLC59208F TLC59208F_4;

    static LSM9DS1 LSM9DS1_1;

    static BME280 BME280_1;

    static Timer Timer2;

    static void clock_init(void);
    static void QSPI_init(void);
    static void I2C_init(void);
    static void SPI_init(void);
    static void GPIO_Init(void);
    static void DMA_init();
    static void Timer_init();
    static void NVIC_init(void);
    static void TLC59208F_init(void);
    static void SR_74HC595_init(void);
    static void LSM9DS1_init();

    static void init(void);

    static bool up;
    static bool down;
    static bool left;
    static bool right;

private:
    HAL() = delete;
};
#endif /* HAL_HAL_HPP_ */

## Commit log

2018-08-19 Init Commit
    [Display.sch, MosfetMultiplexer.sch, woodenClock.kicad_pcb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]
2018-08-21 Moved schematics and laeyot to Hardware/Electronics
    [Display.sch, MosfetMultiplexer.sch, woodenClock.kicad_pcb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]
2018-08-21 deleted moved files
    [Display.sch, MosfetMultiplexer.sch, woodenClock.kicad_pcb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]
2018-08-21 Added files for the enclouser design
    [DisplayBoard.FCStd, FacePlate.FCStd, SidePlate.FCStd]
2018-10-21 Added combined model of the housing
    [Combined.FCStd]
2018-10-21 Changed dispaly board schematic and layout version to 1.0.0 Moved vias from the capacitor pads Added github link on the silkscreen Changed files architecture Pushed new gerbers
    [DispalyBoard-B.Cu.gbr, DispalyBoard-B.Mask.gbr, DispalyBoard-B.SilkS.gbr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]
2018-11-18 added CMSIS for stm32l452
2019-01-13 Added wrapper template class for the I2C
2019-01-17 Added method for setting the I2C timming
2019-01-17 using set_timing method for the I2Cs
2019-02-15 Added DMA,Dsiplay and Clock drafts, added HALL files
2019-02-26 added HAL DMA module
2019-02-28 Added drivers for TLC59208F and 74HC595
2019-02-28 I2C can use DMA, using newly added drivers
2019-03-02 using new DMA interrupt callback function
2019-03-02 Adding interrupt callback possible
2019-03-02 Changed DMA channels
2019-03-09 drivers refactor
2019-03-12 Added Button class
2019-03-12 Added buttons to bsp
2019-03-12 updating buttons in task
2019-05-05 LSM9DS1 driver implementation
2019-05-05 SPI wrapper
2019-05-05 Schematic update -- start of the main board designe
    [DisplayBoard.sch, Displays.sch, MainBoard.sch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]
2019-06-08 Draft of the magnetometer class
2020-05-03 Changed pullup resistors on the gates of mosfets to 4k7 - faster gate discharge
    [DispalyBoard.kicad_pcb, DisplayBoard.sch, Displays.sch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]
2020-05-03 Added main board design
    [MainBoard-B.Cu.gbr, MainBoard-B.Mask.gbr, MainBoard-B.SilkS.gbr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]
2020-05-03 Added button board design
    [ButtonBoard-B.Cu.gbr, ButtonBoard-B.Mask.gbr, ButtonBoard-B.SilkS.gbr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]
2020-05-03 added methods for checking WHO_AM_I registers, turned on gyro on init
2020-05-03 added methods for cashing led vealues before sending them
2020-05-03 BME280 drivers
2020-05-03 addedmethod to add half transfer interrupt callback
2020-05-03 Addapted to the PCB design, QSPI test, reciving data from ESP
2020-05-03 Accelerometer place holder
2020-05-03 Gyroscope place holder
2020-05-20 set value of the capacitor on the button board, changed resitor value on the display board
    [ButtonBoard.sch, MosfetMultiplexer.sch]
2020-05-20 new screen to test buttons, touch buttons handling
2021-02-01 fixed buttons
2021-02-02 Correct buttons names
2025-07-27 updated schematics
    [ButtonBoard.kicad_pcb, ButtonBoard.kicad_sch, DispalyBoard.kicad_pcb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]
2025-10-04 Fixed typos and clang findings
    [Clock.cpp, HAL.cpp, TLC59208F.cpp]
2025-10-18 Extended USART class
    Now it can handle rx not empty and idle interrupts
2025-10-18 DMA requests setup handling
2025-10-19 removed cmsis header form i2c class
2025-10-19 Added minimal power class
2025-12-02 Kicad files cleanup
    [ButtonBoard.kicad_pcb, ButtonBoard.kicad_sch, ButtonBoard.sch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]
2026-05-09 fix some more clang-tidy findings
    [LSM9DS1.cpp, TLC59208F.cpp, main.cpp]
2026-05-11 Added arduino stuff to docker image
2026-05-11 fixed arduino build step
2026-05-12 Switched to platformio
2026-05-14 Added clearing all USART interrupts so the program isnt getting stuck
    [USART.cpp]
2026-05-26 Add method for sending data over UART
2026-05-26 Handling UART4 interrupt
2026-05-26 Added S25FL129 driver draft
2026-11-04 Flasher: STM32L452 consts
2026-11-05 STM: HAL: extended timer
2026-11-05 STM: DMA interrupt
2026-11-12 Flasher: STM32L452_info: annotations
2026-11-12 Bootloader: UART
